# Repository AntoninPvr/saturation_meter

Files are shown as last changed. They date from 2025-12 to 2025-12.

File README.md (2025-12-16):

# Saturation meter

A simple saturation meter to estimate the saturation current of inductors.

This project is a quick and dirty implementation, and is not intended for production use. I need to measure the saturation current of some inductors for a project, so I built this tool to help me do that.

I used only parts I had lying around, and I want to use isolation milling, so the design is not optimal.

## Assembly

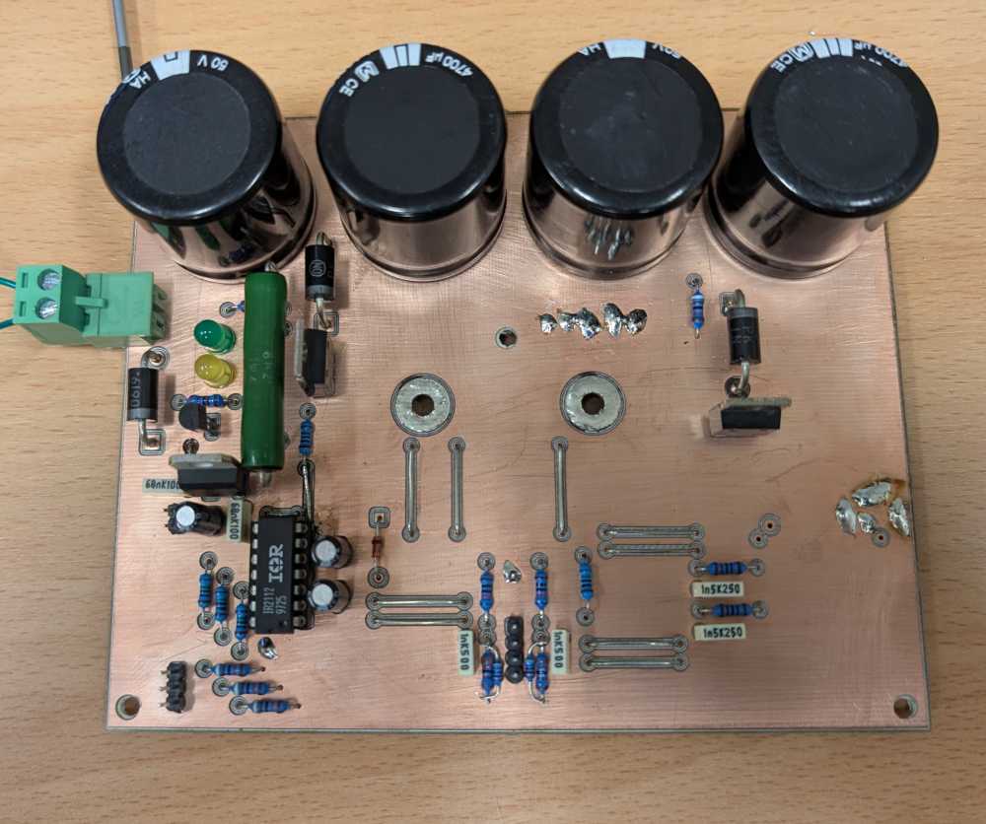
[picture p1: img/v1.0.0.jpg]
Assembly


## 3D Model

To protect the circuit, I designed a simple enclosure that can be 3D printed. and laser cut.

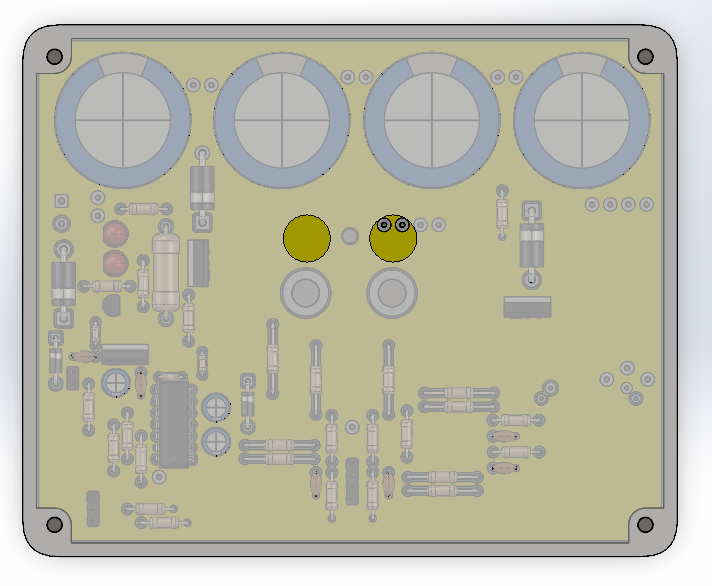
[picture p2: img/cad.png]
cad


All files are in the `cad` folder.

- [bottom.stl](cad/bottom.stl)

- [sides.stl](cad/sides.stl)

- [top.svg](cad/top.svg) (for laser cutting red 0.2mm stroke)

## Design

It is based on a discussion on the EEVblog forum: https://www.eevblog.com/forum/beginners/help-with-testing-inductor-saturation-current/
The idea is to discharge a capacitor through the inductor and measure the voltage and current across the inductor. When the inductor saturates, the dI/dt increases, (ie L decreases).

To measure the voltage and current, I use a STM32F103 with its built-in ADC. I choose to not use any op-amps to keep the design simple.

### MOSFETs

I use two N-channel MOSFETs (BUK556), they are driven by the IR2112, but not in the usual half-bridge configuration.

The low-side MOSFET (Q2) is ON before the high-side MOSFET (Q1) in order to charge the bootstrap capacitor (C12). Then Q1 is turned ON to let current flow through the inductor under test.

Almost any N-channel MOSFET with a Vds rating of at least 30V and a low Rds(on) will work. For the bootstrap capacitor (C12), I recommend at least 1uF. Because the ON time of Q1 is relatively long compared to a typical half-bridge application, a larger capacitor will help maintain the gate voltage.

### Current sensing

I don't have a proper shunt resistor, so I made a shunt using PCB traces. The shunt resistor (R9) is designed to have a resistance of **60mΩ with a 1oz** PCB. Keep in mind that the copper thermal coefficient of resistance is poor, so the resistance will vary with temperature. But because the current is measured over a short period of time, the temperature rise should be minimal.

You will need to calibrate the shunt resistor by measuring the voltage drop across it at a known current, because the actual resistance may vary due to manufacturing tolerances (especially with isolation milling).

### LEDs

Two LEDs give visual feedback about the operation of the circuit:

- D5 (green): indicates that the circuit is powered.
- D6 (yellow): inidicates that the capacitor bank is being charged.

## Schematic

Schematic

## Layout

The layout is designed for isolation milling. It complies with the following rules:

- Minimum trace width: 0.2mm (recommended: 0.3mm)
- Minimum clearance: 0.3mm
- No plated through holes

I choose a **single layer design** to keep it simple, therefore traces routed on the top layer are straps. Nevertheless, I added front copper plane because the LPKG S63 I use is able to do double layer PCB. Because I cant do vias, I had to add some **jumpers to connect the top and bottom layers**.

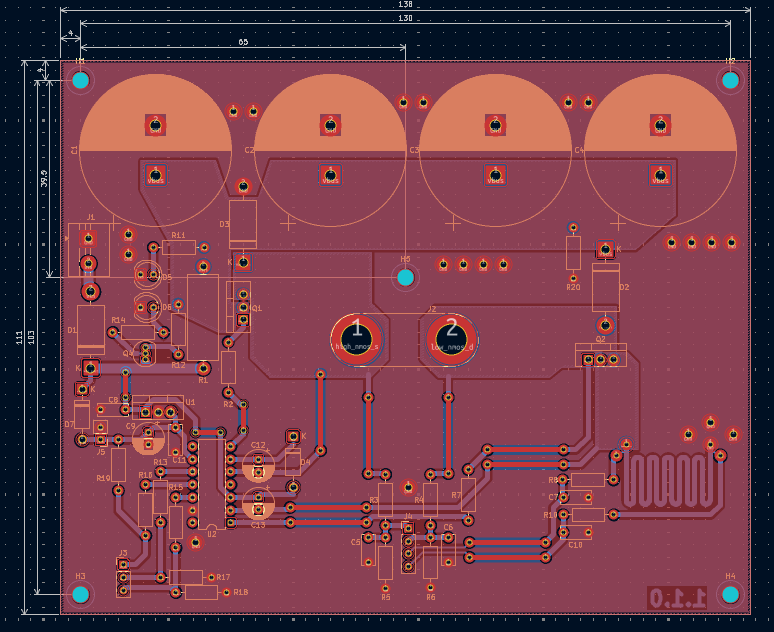
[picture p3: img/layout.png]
Layout


## BOM

Use the [interactive BOM viewer](ibom.html)

| Reference | Qty | Value | Footprint |
|---|-----|---|---|
| C1,C2,C3,C4 | 4 | 4700u | Capacitor_THT:CP_Radial_D30.0mm_P10.00mm_SnapIn |
| C5,C6,C7,C10 | 4 | 1n | Capacitor_THT:C_Disc_D6.0mm_W2.5mm_P5.00mm |
| C8,C11 | 2 | 100n | Capacitor_THT:C_Disc_D6.0mm_W2.5mm_P5.00mm |
| C9,C12,C13 | 3 | 2u2 | Capacitor_THT:CP_Radial_D6.3mm_P2.50mm |
| D1,D2,D3 | 3 | 1N5822 | Diode_THT:D_DO-201AD_P15.24mm_Horizontal |
| D4,D7 | 2 | 1N4007 | Diode_THT:D_DO-41_SOD81_P10.16mm_Horizontal |
| D5,D6 | 2 | LED | LED_THT:LED_D5.0mm |
| H1,H2,H3,H4,H5 | 5 | MountingHole | MountingHole:MountingHole_3.2mm_M3_DIN965 |
| J1 | 1 | Vin | TerminalBlock:TerminalBlock_MaiXu_MX126-5.0-02P_1x02_P5.00mm |
| J2 | 1 | DUT | Connector:Banana_Jack_2Pin |
| J3 | 1 | Inputs | Connector_PinHeader_2.54mm:PinHeader_1x03_P2.54mm_Vertical |
| J4 | 1 | Outputs | Connector_PinHeader_2.54mm:PinHeader_1x04_P2.54mm_Vertical |
| J5 | 1 | UC | Connector_PinHeader_2.54mm:PinHeader_1x02_P2.54mm_Vertical |
| Q1,Q2 | 2 | BUK556 | Package_TO_SOT_THT:TO-220-3_Vertical |
| Q4 | 1 | BC638 | Package_TO_SOT_THT:TO-92_Inline |
| R1 | 1 | 10 | Resistor_THT:R_Axial_DIN0617_L17.0mm_D6.0mm_P20.32mm_Horizontal |
| R2,R7,R13,R15,R16 | 5 | 100 | Resistor_THT:R_Axial_DIN0207_L6.3mm_D2.5mm_P10.16mm_Horizontal |
| R3,R4,R12,R17,R18,R19,R20 | 7 | 8k2 | Resistor_THT:R_Axial_DIN0207_L6.3mm_D2.5mm_P10.16mm_Horizontal |
| R5,R6,R11,R14 | 4 | 1k6 | Resistor_THT:R_Axial_DIN0207_L6.3mm_D2.5mm_P10.16mm_Horizontal |
| R8,R10 | 2 | 1k | Resistor_THT:R_Axial_DIN0207_L6.3mm_D2.5mm_P10.16mm_Horizontal |
| R9 | 1 | 60m | shunt:R_Shunt_kelvin_60mohm |
| U1 | 1 | LF33_TO220 | Package_TO_SOT_THT:TO-220-3_Vertical |
| U2 | 1 | IR2112 | Package_DIP:DIP-14_W7.62mm |

## Firmware

The firmware is available on its dedicated repository: https://github.com/AntoninPvr/saturation_meter_firmware

## ToDo

- [ ] Add test results

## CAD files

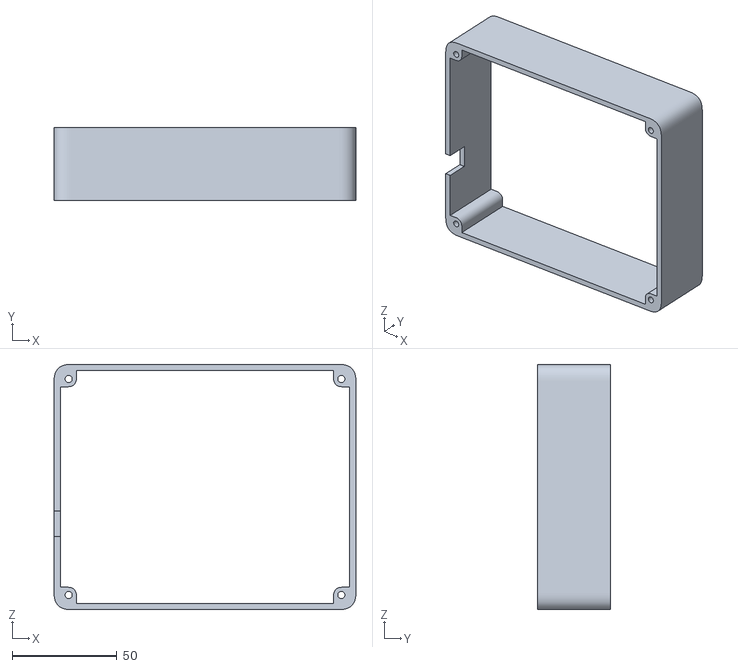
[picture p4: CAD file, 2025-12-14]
cad/sides.STL
144.0 x 35.0 x 117.0

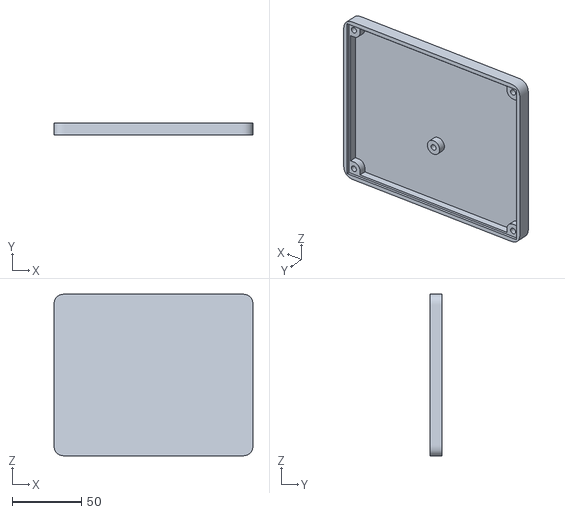
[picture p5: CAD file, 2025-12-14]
cad/bottom.STL
144.0 x 8.80 x 117.0

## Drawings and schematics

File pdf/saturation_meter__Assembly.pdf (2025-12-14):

4 39.5 103

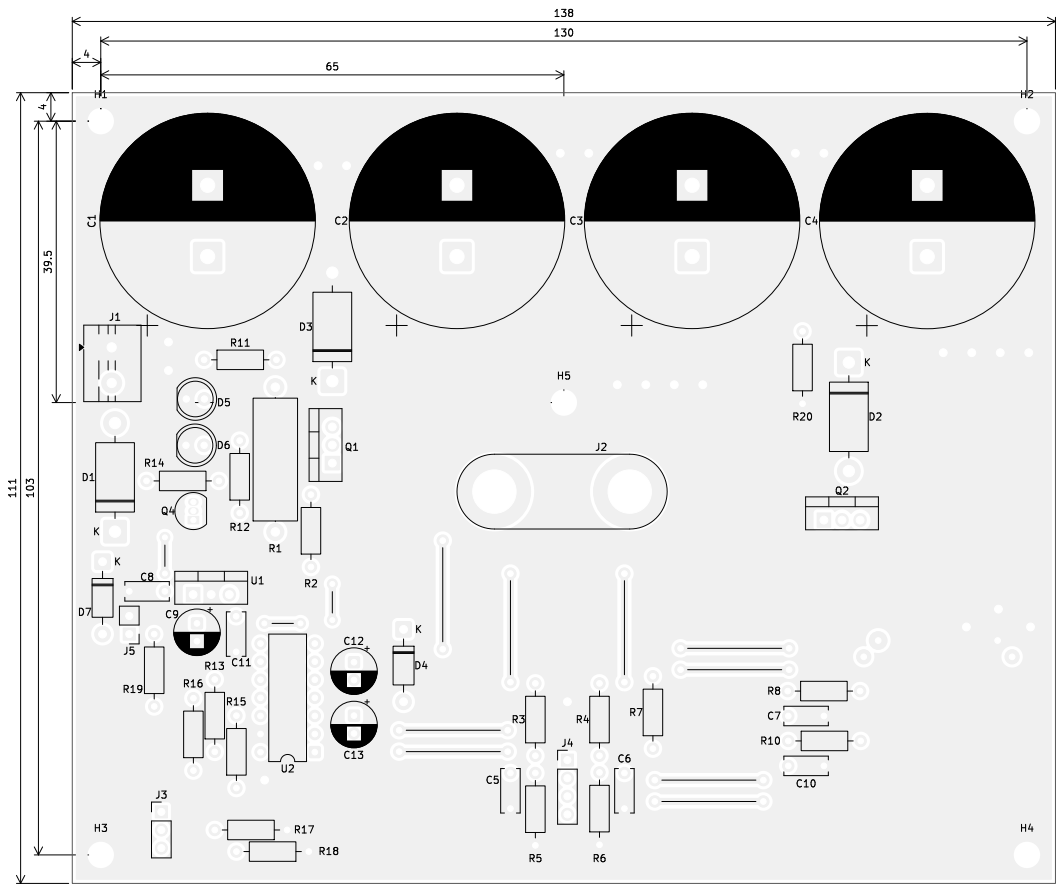
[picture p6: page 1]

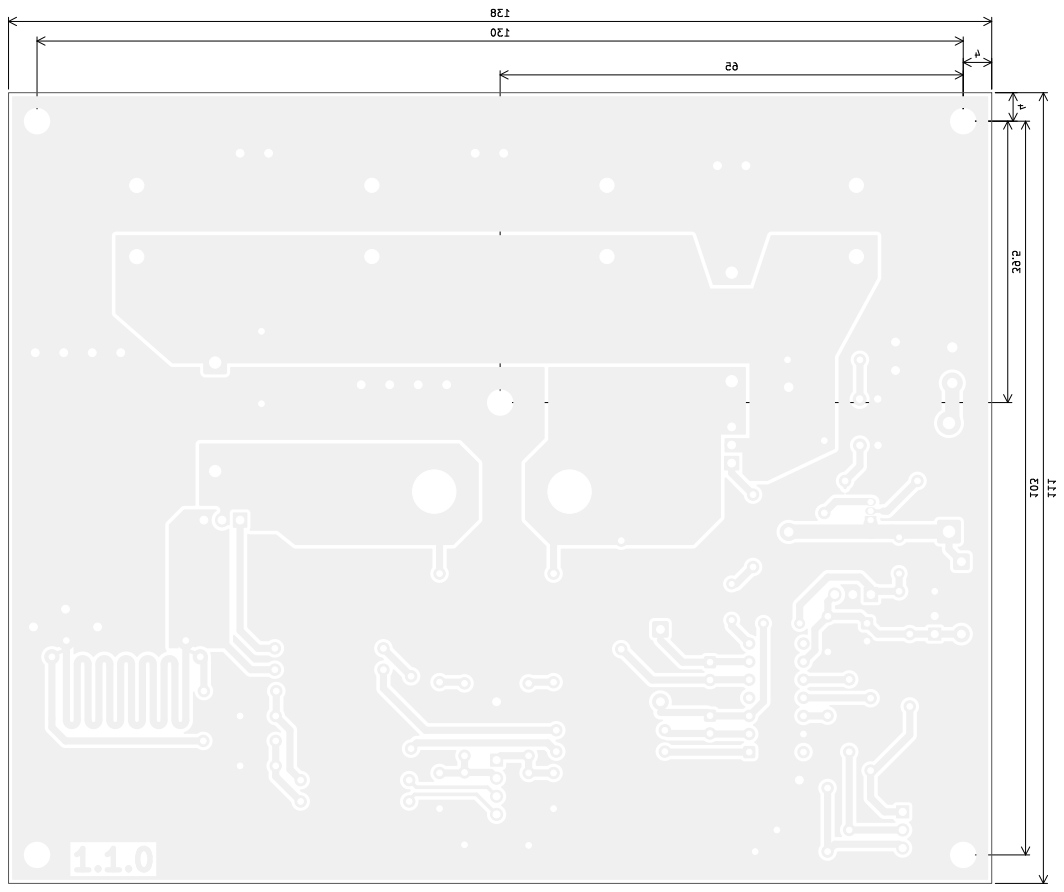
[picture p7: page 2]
D Date: 2025-12-14 KiCad; E.D.A. 9.0.6 Size: A4; Rev: 1.1.0; Id: /1 Title: Saturation meter File: saturation_meter.kicad_pcb Sheet: Black; And; White; BOT; For; Isolation; milling Board2Pdf:; Black; BOT -; Page 2/2

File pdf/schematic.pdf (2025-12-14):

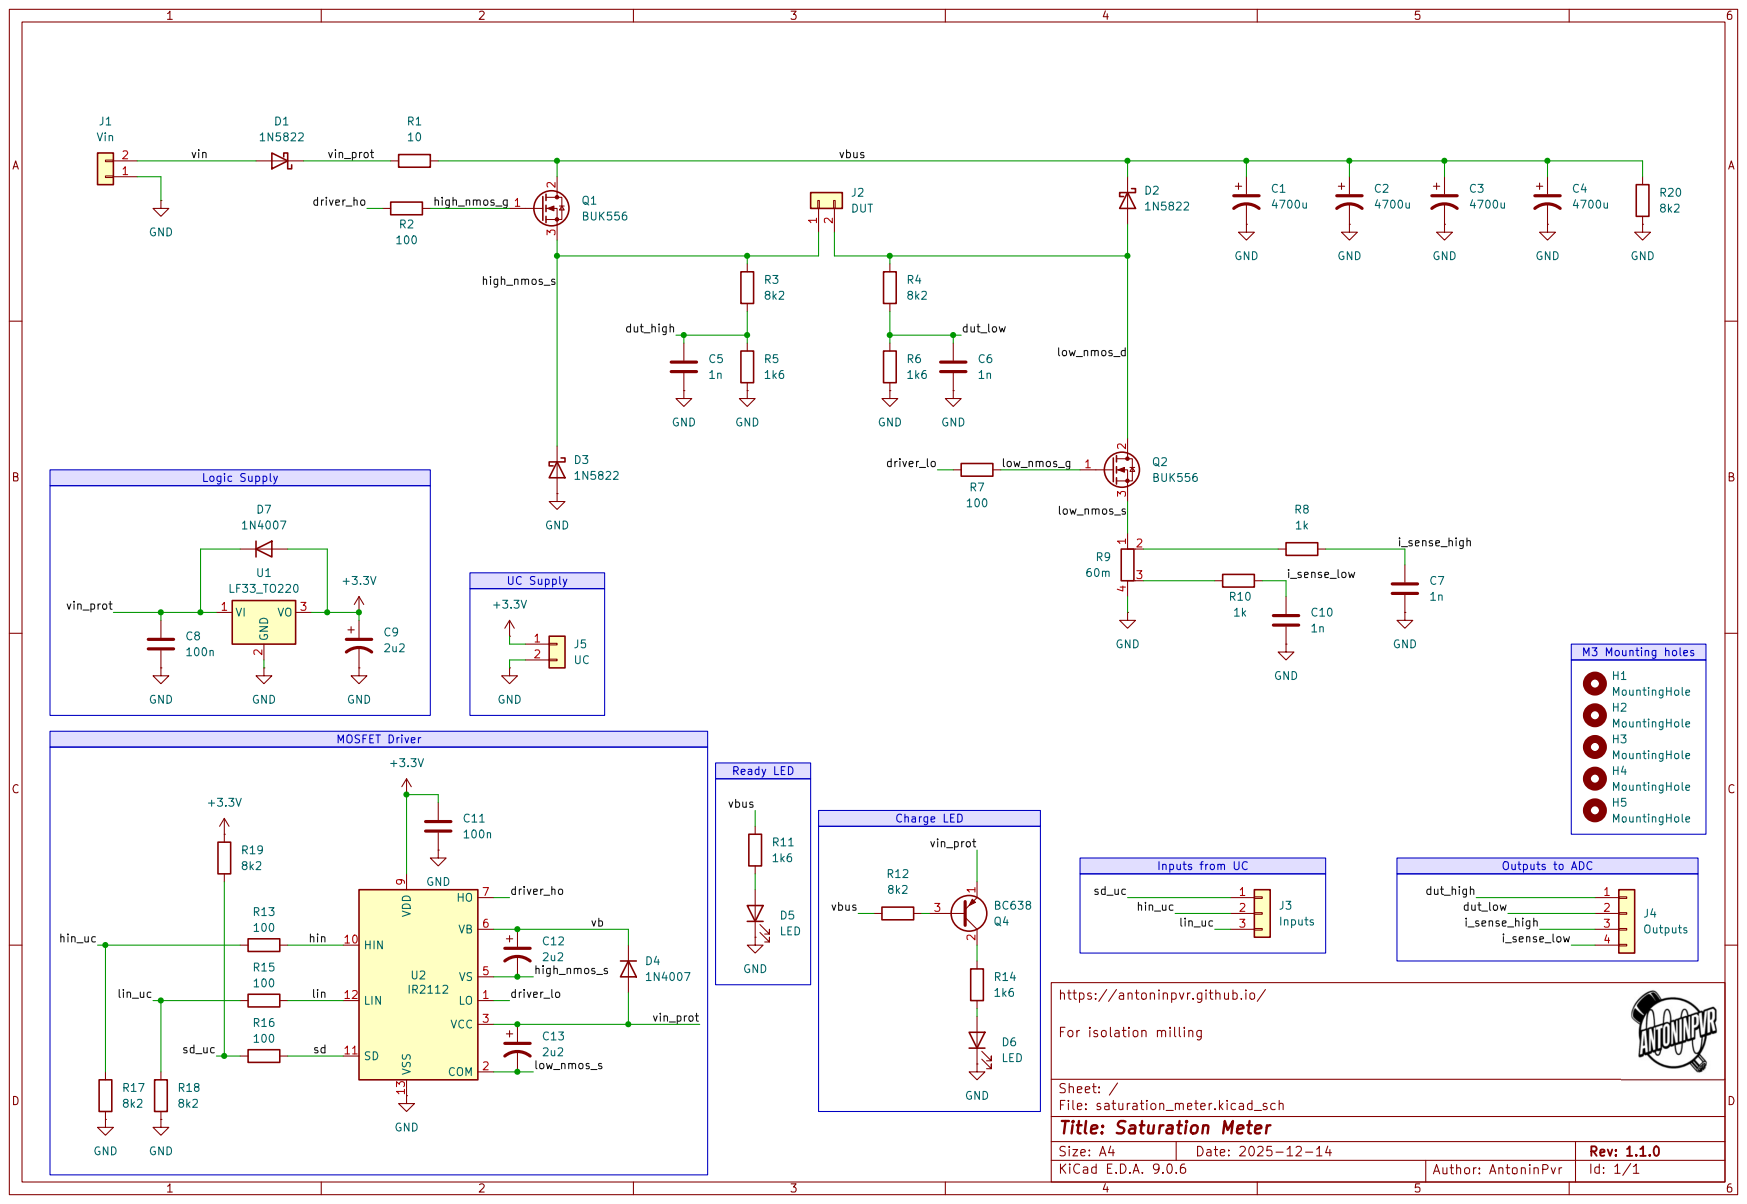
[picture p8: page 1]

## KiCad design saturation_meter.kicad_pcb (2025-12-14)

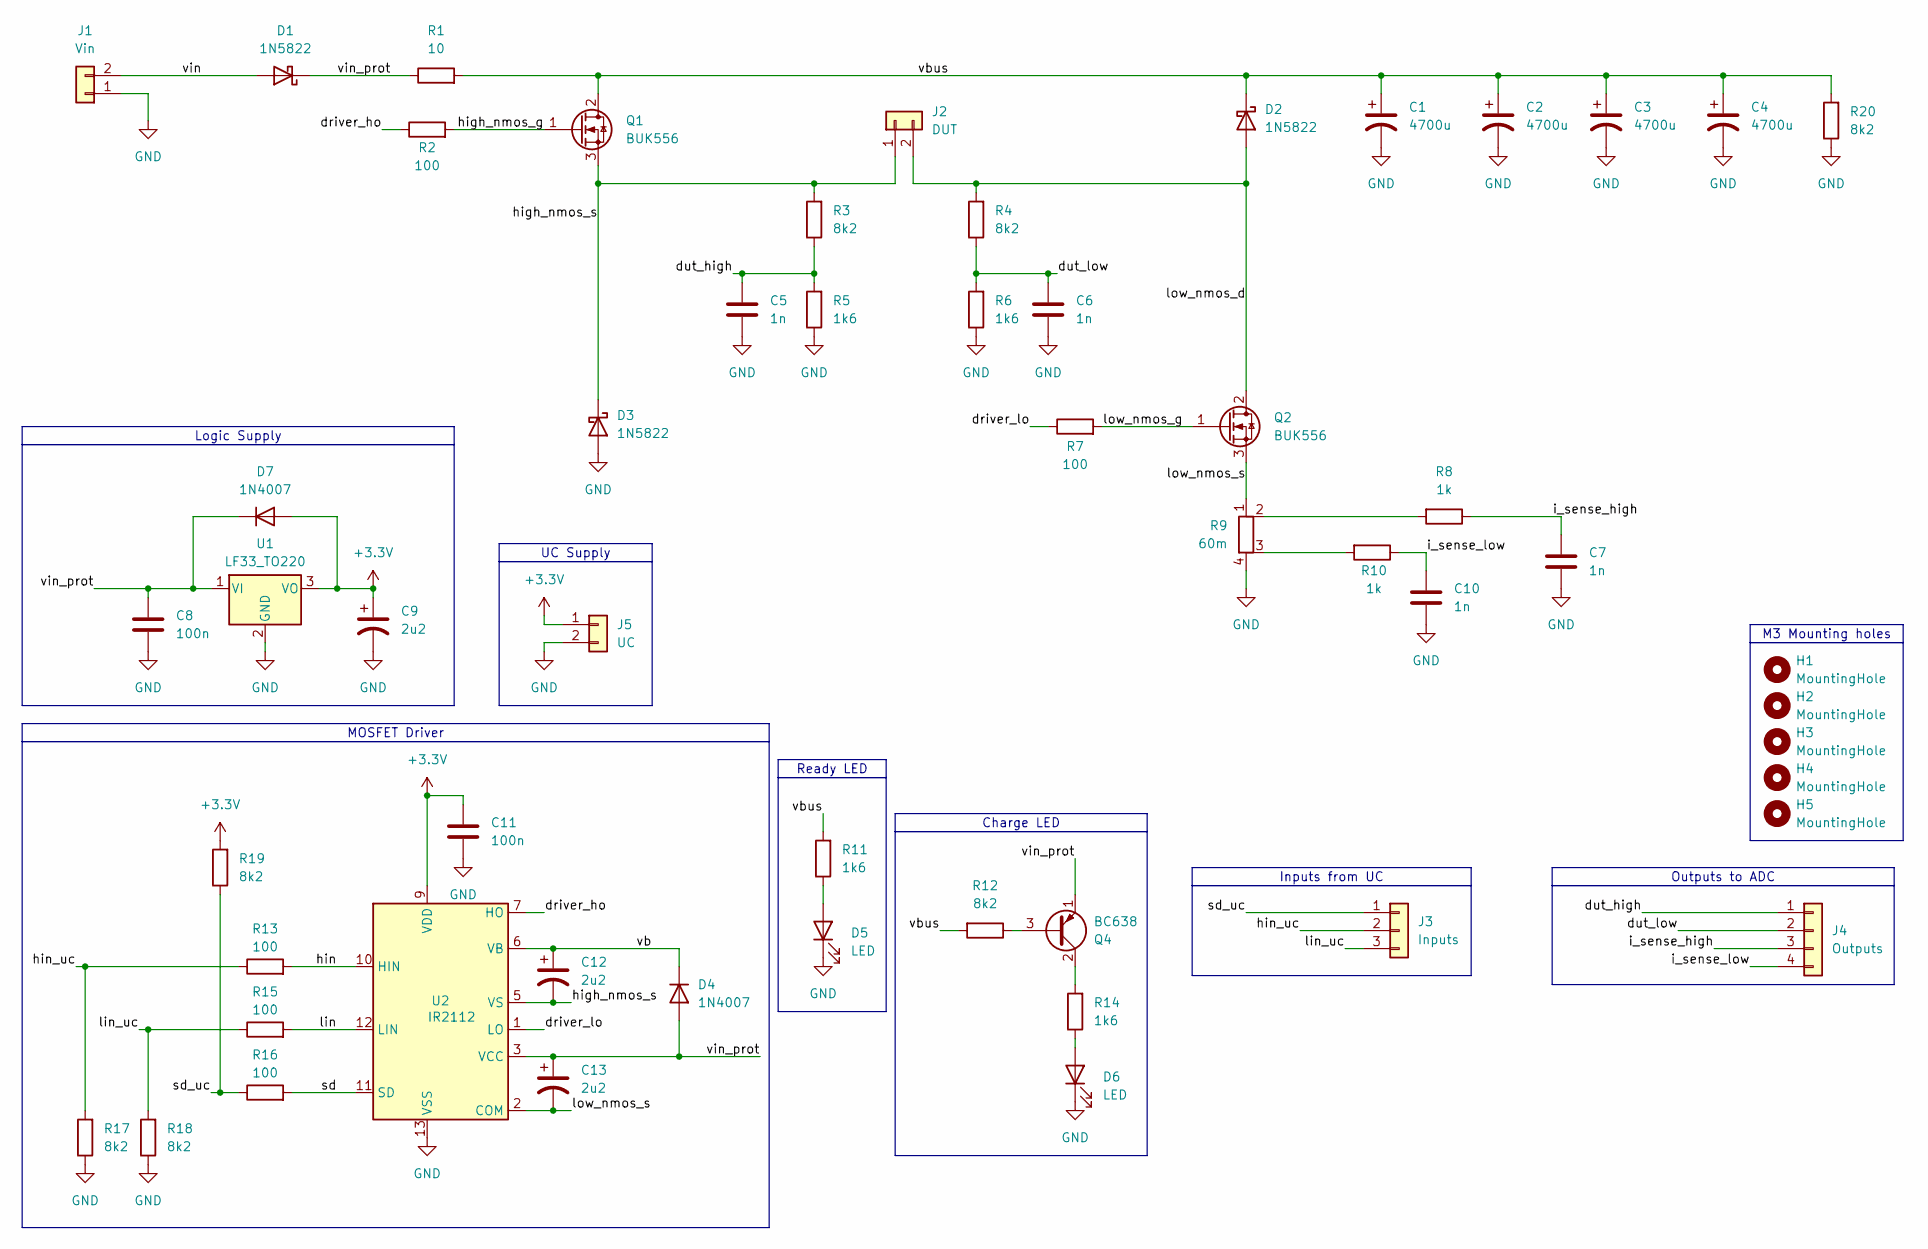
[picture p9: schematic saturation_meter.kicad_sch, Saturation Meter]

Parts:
C1, C2, C3, C4: 4700u; CP_Radial_D30.0mm_P10.00mm_SnapIn
C5, C6, C7, C10: 1n; C_Disc_D6.0mm_W2.5mm_P5.00mm
C8, C11: 100n; C_Disc_D6.0mm_W2.5mm_P5.00mm
C9, C12, C13: 2u2; CP_Radial_D6.3mm_P2.50mm
D1, D2, D3: 1N5822; D_DO-201AD_P15.24mm_Horizontal
D4, D7: 1N4007; D_DO-41_SOD81_P10.16mm_Horizontal
D5, D6: LED; LED_D5.0mm
H1, H2, H3, H4, H5: MountingHole; MountingHole_3.2mm_M3_DIN965
J1: Vin; TerminalBlock_MaiXu_MX126-5.0-02P_1x02_P5.00mm
J2: DUT; Banana_Jack_2Pin
J3: Inputs; PinHeader_1x03_P2.54mm_Vertical
J4: Outputs; PinHeader_1x04_P2.54mm_Vertical
J5: UC; PinHeader_1x02_P2.54mm_Vertical
Q1, Q2: BUK556; TO-220-3_Vertical
Q4: BC638; TO-92_Inline
R1: 10; R_Axial_DIN0617_L17.0mm_D6.0mm_P20.32mm_Horizontal
R2, R7, R13, R15, R16: 100; R_Axial_DIN0207_L6.3mm_D2.5mm_P10.16mm_Horizontal
R3, R4, R12, R17, R18, R19, R20: 8k2; R_Axial_DIN0207_L6.3mm_D2.5mm_P10.16mm_Horizontal
R5, R6, R11, R14: 1k6; R_Axial_DIN0207_L6.3mm_D2.5mm_P10.16mm_Horizontal
R8, R10: 1k; R_Axial_DIN0207_L6.3mm_D2.5mm_P10.16mm_Horizontal
R9: 60m; R_Shunt_kelvin_60mohm
U1: LF33_TO220; TO-220-3_Vertical
U2: IR2112; DIP-14_W7.62mm

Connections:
+3.3V: C9.1, C11.1, D7.2 (A), J5.1, R19.2, U1.3 (VO), U2.9 (VDD)
/driver_ho: R2.1, U2.7 (HO)
/driver_lo: R7.1, U2.1 (LO)
/dut_high: C5.1, J4.1, R3.1, R5.2
/dut_low: C6.1, J4.2, R4.1, R6.2
/high_nmos_g: Q1.1 (G), R2.2
/high_nmos_s: C12.2, D3.1 (K), J2.1, Q1.3 (S), R3.2, U2.5 (VS)
/hin: R13.2, U2.10 (HIN)
/hin_uc: J3.2, R13.1, R17.2
/i_sense_high: C7.1, J4.3, R8.1
/i_sense_low: C10.1, J4.4, R10.1
/lin: R15.2, U2.12 (LIN)
/lin_uc: J3.3, R15.1, R18.2
/low_nmos_d: D2.2 (A), J2.2, Q2.2 (D), R4.2
/low_nmos_g: Q2.1 (G), R7.2
/low_nmos_s: C13.2, Q2.3 (S), R9.1, U2.2 (COM)
/sd: R16.2, U2.11 (SD)
/sd_uc: J3.1, R16.1, R19.1
/vb: C12.1, D4.1 (K), U2.6 (VB)
/vbus: C1.1, C2.1, C3.1, C4.1, D2.1 (K), Q1.2 (D), R1.2, R11.2, R12.2, R20.2
/vin: D1.2 (A), J1.2
/vin_prot: C8.1, C13.1, D1.1 (K), D4.2 (A), D7.1 (K), Q4.1 (E), R1.1, U1.1 (VI), U2.3 (VCC)
GND: C1.2, C2.2, C3.2, C4.2, C5.2, C6.2, C7.2, C8.2, C9.2, C10.2, C11.2, D3.2 (A), D5.1 (K), D6.1 (K), J1.1, J5.2, R5.1, R6.1, R9.4, R17.1, R18.1, R20.1, U1.2 (GND), U2.13 (VSS)
unnamed: D5.2 (A), R11.1
unnamed: D6.2 (A), R14.1
unnamed: Q4.3 (B), R12.1
unnamed: Q4.2 (C), R14.2
unnamed: R8.2, R9.2
unnamed: R9.3, R10.2

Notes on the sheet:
Ready LED
UC Supply
M3 Mounting holes
Charge LED
Logic Supply
Inputs from UC
Outputs to ADC
MOSFET Driver

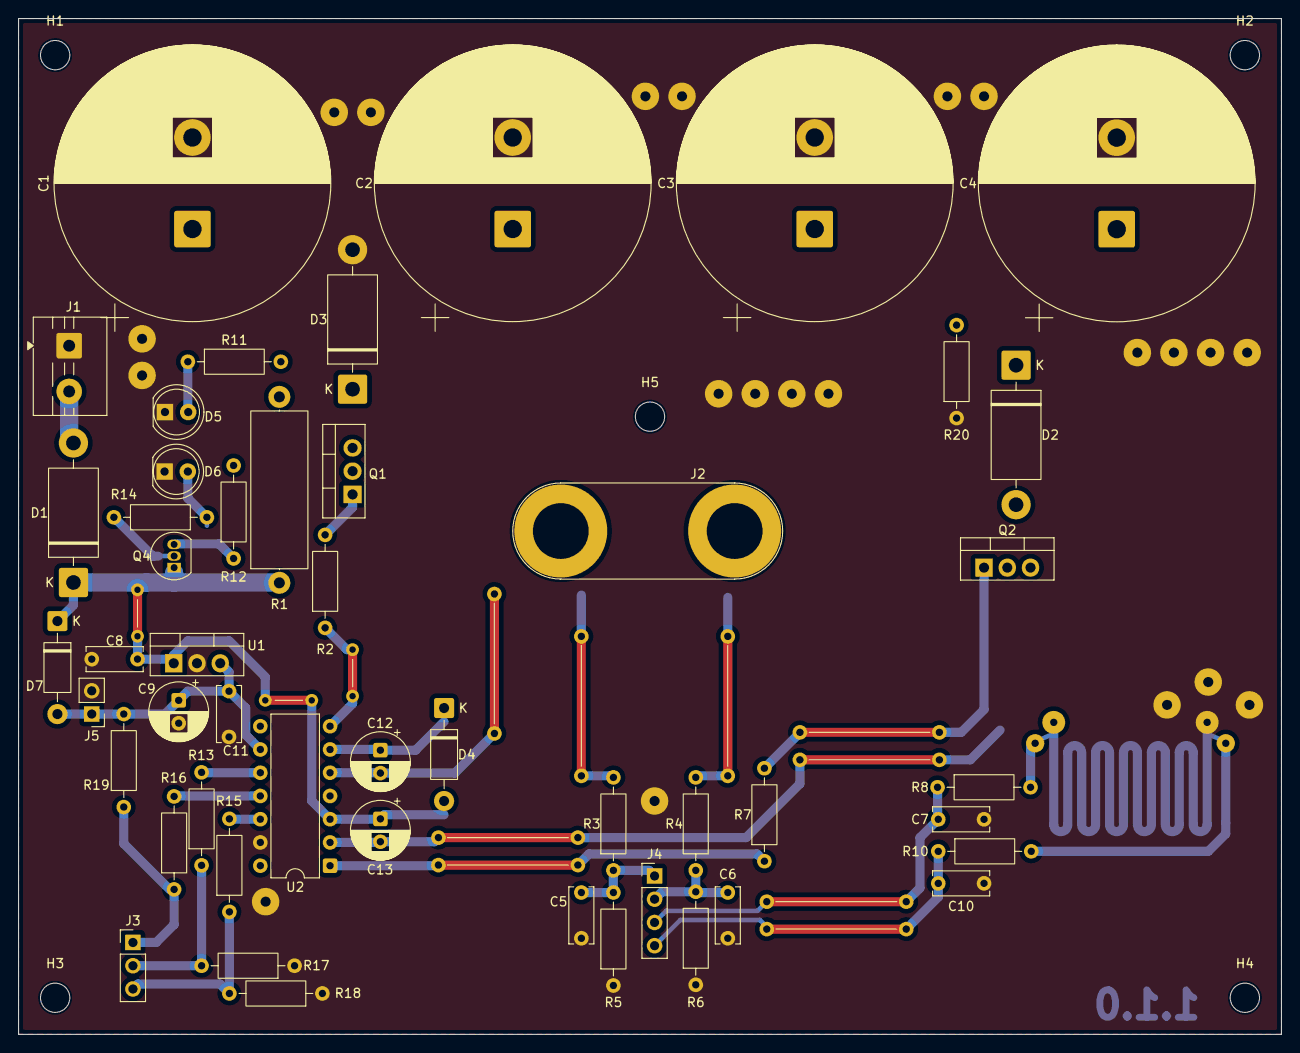
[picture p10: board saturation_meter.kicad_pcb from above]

Board: 2 copper layers, 138.0 x 111.0 mm, 55 parts (0 on the bottom side), 29 nets.

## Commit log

2025-12-09 Added cap
    [saturation_meter.kicad_sch]
2025-12-09 Released 1.0.0 of schematic
    [saturation_meter.kicad_pcb, saturation_meter.kicad_sch]
2025-12-10 First version of PCB, ready to isolation milling
    [saturation_meter.kicad_pcb, saturation_meter.kicad_sch]
2025-12-10 Added version number
    [saturation_meter.kicad_pcb]
2025-12-10 Added schematic.pdf and readme
2025-12-10 Added pictures and updated design sheet
    [saturation_meter.kicad_pcb]
2025-12-11 Added production files for back layer
    [saturation_meter.kicad_pcb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]
2025-12-11 Updated to double layer
    [saturation_meter.kicad_pcb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]
2025-12-14 Updated to v1.1.0 fixed, shutdown of ir2112, added enclosure
    [bottom.STL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]
2025-12-16 Added BOM.csv
